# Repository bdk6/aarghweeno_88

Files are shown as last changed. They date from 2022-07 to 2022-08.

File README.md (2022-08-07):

# aarghweeno_88
An Arduino compatible prototyping board

Short story: add prototyping area to Arduino compatible AVR development board.

I have been a fan of the AVR processors for a long time.  My first project with them was in 2006.  The Arduino came along later and it is a neat system, making it very easy to get started.  When I say "Arduino" I mean AVR based ones.  If I should refer to some other, I'll specify.  

Now you can get an Aruino Nano clone for less than $5 US all over the web.  But one thing that has often bothered me about all the standard Arduino boards is that they don't have onbaord prototyping areas.  This little project aims to fix that.

The board is 3.9 x 3.9 inches, just under the 100 x 100 mm size of JLCPCBs cheapest PC board service.  About 1 1/2 inch along the "top" edge holds the AVR, regulator, programming header, and associated components.  The rest of the board is taken up with a prototyping area of holes on 0.1" centers arranged in groups of threes and long rows of bus connections.  There are also four mounting holes, another thing absent from standard Arduinos.  The idea is you can build an entire project on a single board without all those "dupont" (I hate that name) wires and whatnot crap going from board to board.

The one thing I left off that I agonized over was a USB interface or any type of serial port circuit.  Many of my projects don't need either and I generally prefer to use an AVR programmer to flash the chip.  If you really need/want a USB interface you can add it in the proto area.  You might need an SMD to DIP adapter or maybe just buy a USB to 5V serial module with 0.1" header pins.

You are welcome to use this board for any purpose, personal or commercial, as long as you leave the copyright notice in place.  I would like to know about any projects you build with it or comments in general.  If you make enough money selling it to hire Bill Gates and Jeff Bezos as your house boys, I wouldn't mind if you slipped me a mil or two.

20220807   First set of boards
I got the first boards back from JLCPCB on Thursday.  Friday morning I started soldering one up.  After replacing the LED that I soldered in backward, everthing seems to be working fine.  A bit more testing to do, but so far, so good.



Today I cleaned up some minor flaws and I'm releasing version 1.1.  Changed to value of C3 (to 0.1 uF from 0.33 uF) and cleaned up some silkscreen.  No substantive changes.  I plan to run a set of these once I've tested the first one more.

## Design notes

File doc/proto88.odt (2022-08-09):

Proto 88 Board

ver 1.1.0

August 7, 2022

Will Cooke

1. Introduction

The Proto-88 board is an AVR development board for use with various 28 pin DIP AVR microcontrollers. The ATMega8, ATMega88, ATMega168, and ATMega328 can all be used. The PC board has onboard circuitry for the basic microcontroller and a large prototyping area. The board is Arduino compatible, but there is no built-in USB circuitry for bootloading.

The hardware design is open source. The gerber files needed to have the board manufactured are available online. Feel free to have as many made as you like. You are welcome to do what you want with them, including selling them. If you do make millions of dollars selling them, please remember where you got it. One stipulation – you MUST keep the copyright notice on the board.

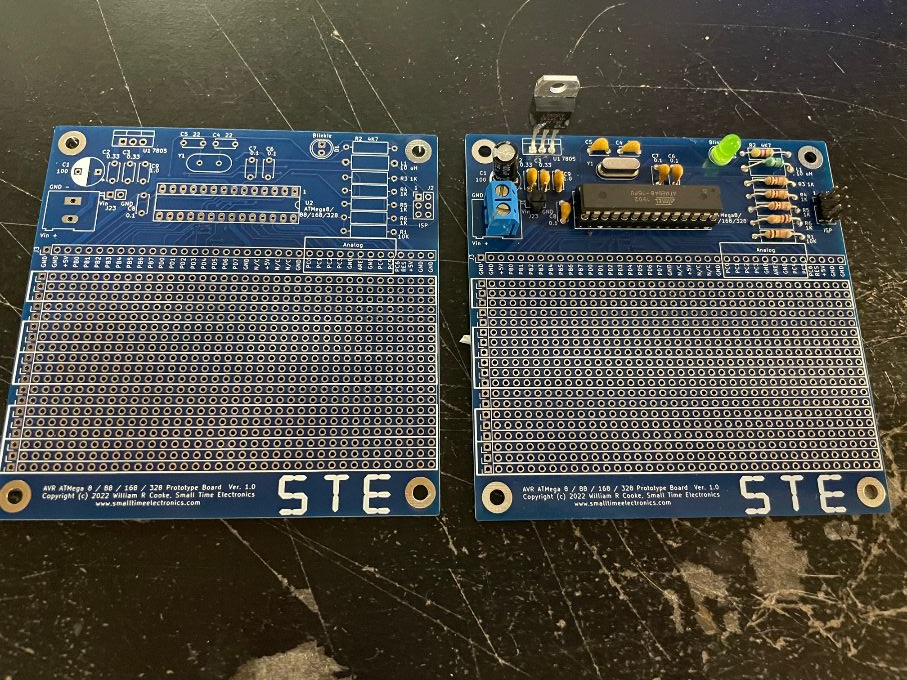
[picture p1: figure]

2. Overview

This is a simple board with just basic necessities of building an AVR project. The board includes the most common things needed and is mostly prototyping area. I have wanted this and intended to build it for a very long time. Before this the two alternatives I had were: 1) build the entire AVR circuit on a common, generic prototyping board, duplicating the same circuitry over and over, and 2) use an Arduino (Nano) and solder it onto a generic proto board. To me, this is a much better solution. I suspect other people will feel the same way.

The board’s features:

- Processor: Can use ATMega8, ATMega88, ATMega168, ATMega328 in narrow DIP 28 package.
- Crystal oscillator circuit.
- Power input connector and filtering.
- Voltage regulator. LM7805 or pin compatible.
- Filtering for Analog VCC.
- Prototyping connections to all processor pins as well as input voltage.
- Programming header (AVR ISP 6 pin.)
- Large prototyping area with 3 hole strips and long power bus strips.
- Arduino compatible.

Schematic and Parts List:

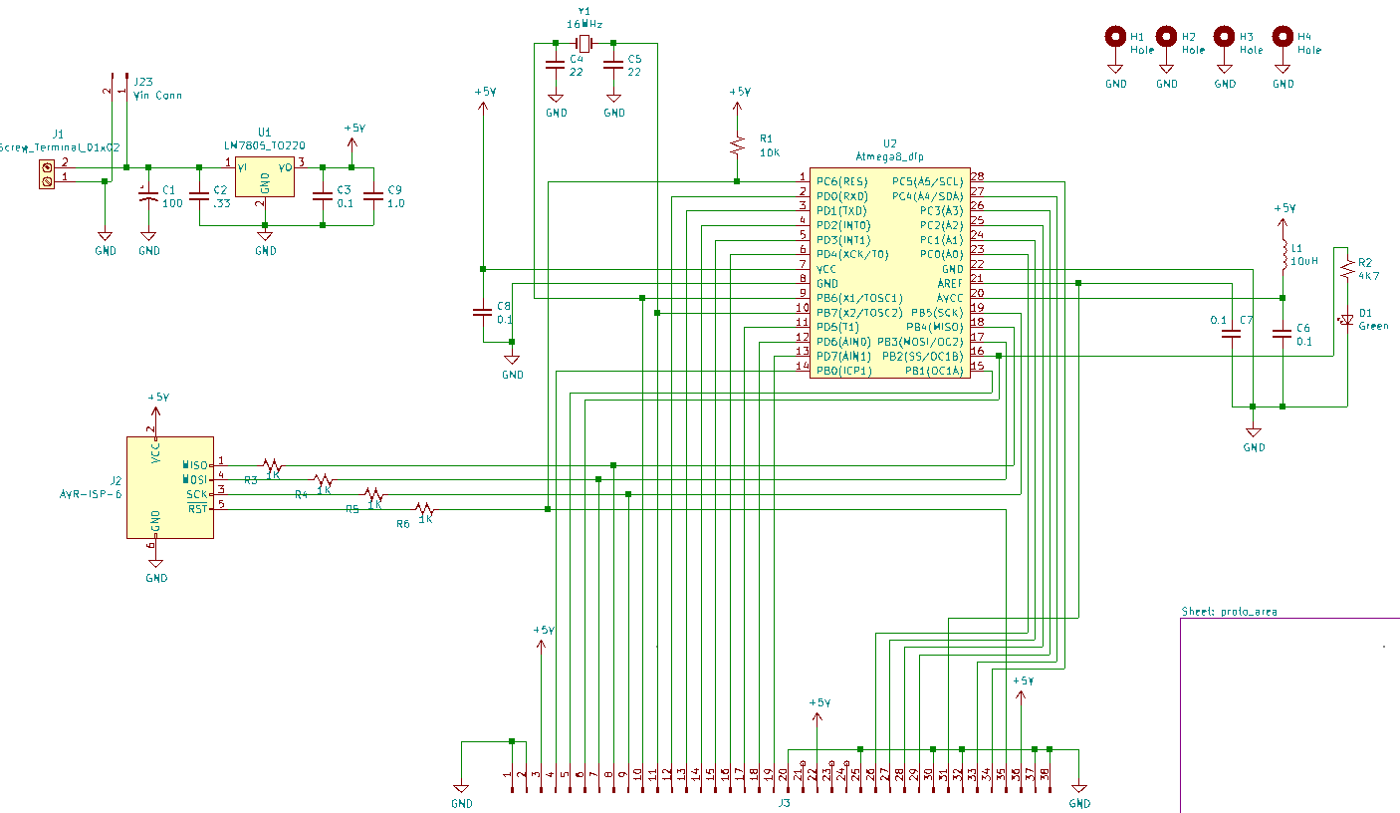
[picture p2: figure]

Parts List

C1 100 uF electrolytic capacacitor 5.04 mm

C2 0.33 uF ceramic capacitor 5.04mm

C3,C6,C7,C8 0.1 uF ceramic capacitor 5.04 mm

C4,C5 22 pF ceramic capacitor 5.04mm

C5 22 pF ceramic capacitor 5.04 mm

C9 1.0 uF ceramic capacitor 5.04 mm

D1 LED, T1 ¾ through hole green

J1 1x2 5mm terminal block

J2 2x3 pin header 2.54 mm AVR ISP connector

J23 1x2 pin header 2.54 mm

L1 10 uH axial leaded inductor (Tayda ???)

R1 10K 1/8 watt through hole

R2 4K7 1/8 watt through hole

R3,R4,R5,R6 1K 1/8 watt through hole

U1` LM7805 TO220 voltage regulator

U2 AVR ATMega8, 48, 88, 168, 328, etc

Y1 16 MHz quartz crystal in HC49 package

Configuration:

power section – It is possible to leave off most of the power input section. The power input terminal block, J1, can be omitted and wires soldered directly to the board. If the board will be powered by a regulated or otherwise acceptable voltage, the LM7805 regulator and C2 and C3 can be left off. A jumper will need to be wired from pin 1 to pin 3 of the regulator position. It’s a good idea to leave C1 and C9 to filter the incoming power. If you have another regulator that is pin compatible, as are many low-dropout regulators, it can be used instead of the LM7805. The two pin header, J23, can be left off in most cases. It connects directly to the power inputs on J1. Its purpose is to make the input power easily available to the prototype area with wires soldered into the holes instead of a header.

CPU – A number of different CPUs can be used. The ATMega8, ATMega88, ATMega168, ATMega328 and probably others (ATMega48, etc) can all be used. They must be in the “narrow” (0.3 inch) 28 pin DIP package. L1 is for filtering the analog to digital converter (ADC) power supply. If you aren’t using the ADC or if the normal CPU power is good enough for your uses, you can replace L1 with a wire jumper and do without the extra filtering. It is recommended to leave the capacitor, C6, in any case.

Programming Header – If for some reason you don’t need the programming header, J2, it and resistors R3, R4, R5, and R6 can be left off.

LED – Under no circumstances should D1 and R2 be left off! People will say bad things about your mother if you build a microcontroller prototyping board without a blinkie light!

The board can be built in many different configurations based on your needs and desires, as well as parts you have on hand.

Prototyping:

They prototype area consists of five rows of 3-hole connected pads on 0.1 inch centers to hold components and wires. Four of the rows are grouped in twos and adjacent to each other to accommodate larger components (e.g. 0.6 inch ICs.) Between the three sections of 3-hole pads are bus strips. There are a total of four strips arranged in two groups of two. The bus strips are independent and not connected to each other or anything else. They would typically be used for power rails (Vcc and GND) but that is not a requirement. You will need to connect them to whatever you desire them to be.

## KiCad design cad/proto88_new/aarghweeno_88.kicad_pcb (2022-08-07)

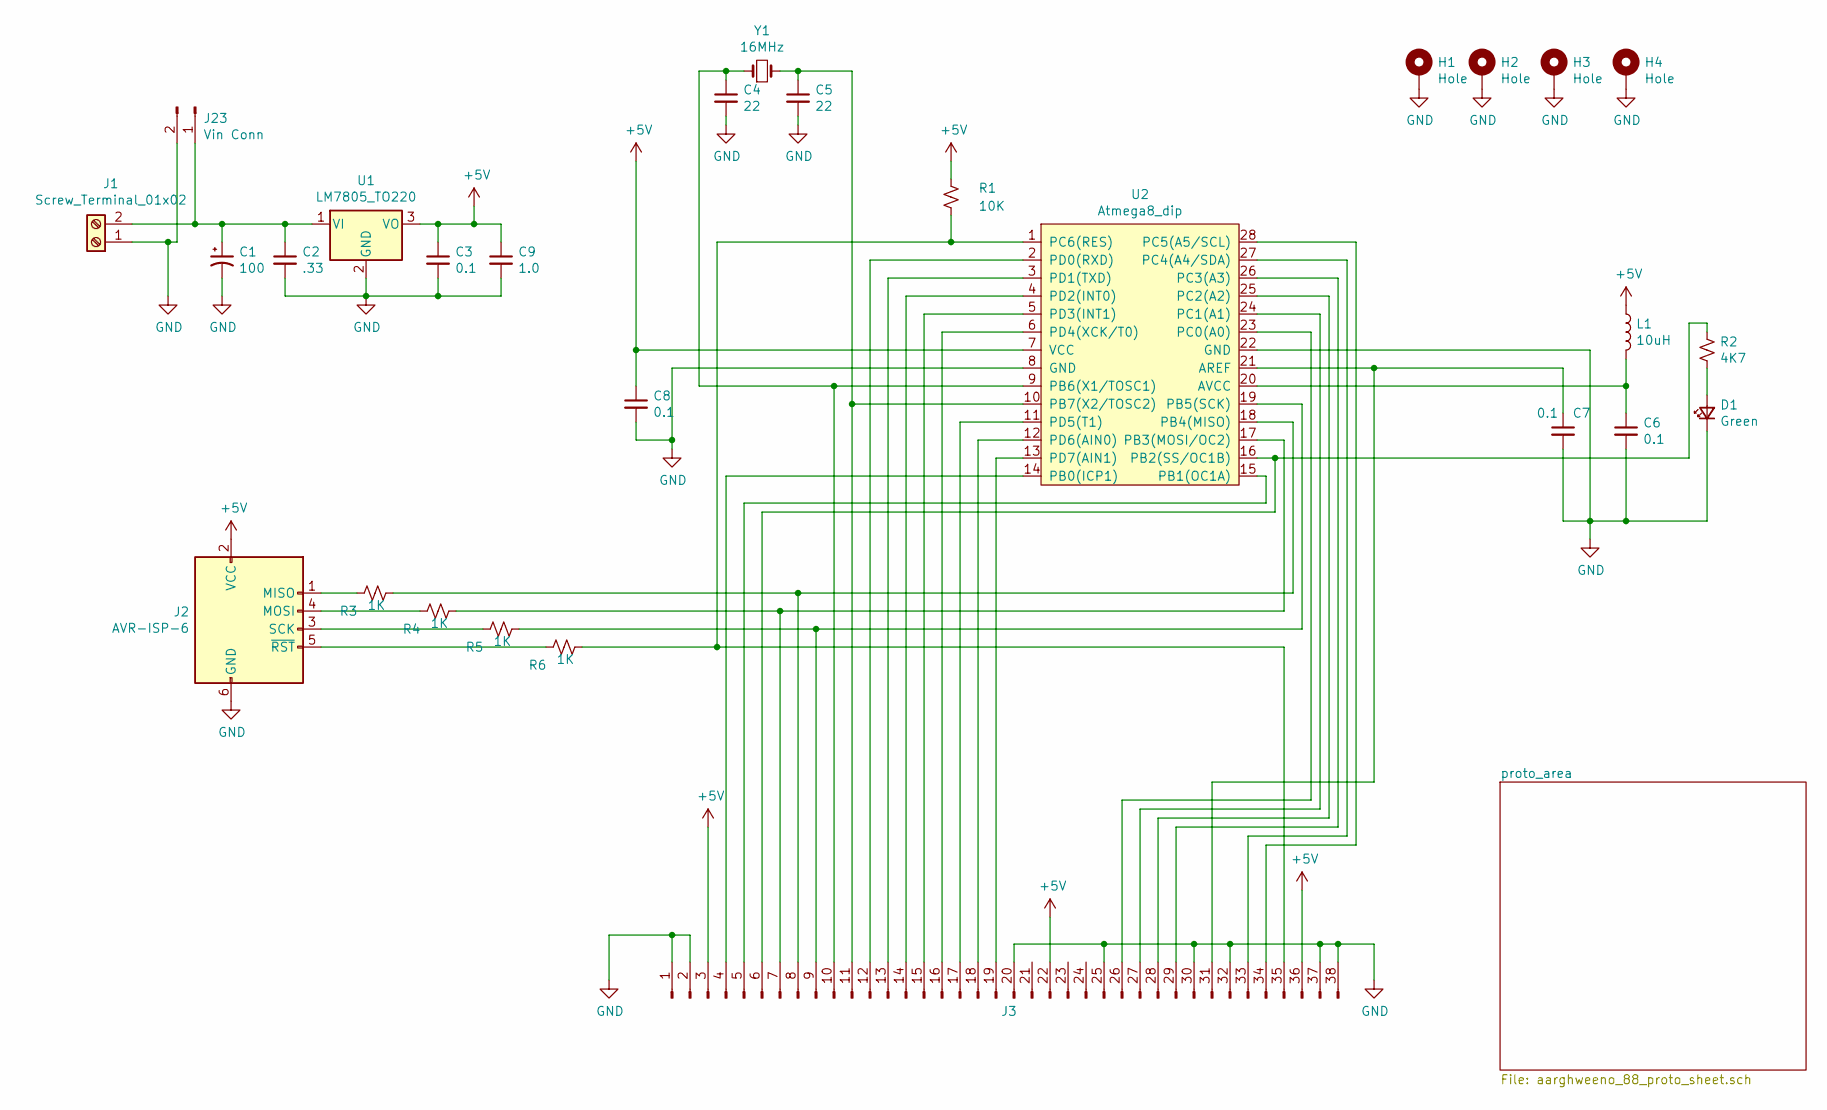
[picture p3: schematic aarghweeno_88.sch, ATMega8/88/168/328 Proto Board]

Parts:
C1: 100; CP_Radial_D8.0mm_P5.00mm
C2: .33; C_Disc_D5.0mm_W2.5mm_P5.00mm
C3, C6, C7, C8: 0.1; C_Disc_D5.0mm_W2.5mm_P5.00mm
C4, C5: 22; C_Disc_D5.0mm_W2.5mm_P5.00mm
C9: 1.0; C_Disc_D5.0mm_W2.5mm_P5.00mm
D1: Green; LED_D5.0mm
H1, H2, H3, H4: Hole; MountingHole_3.5mm_Pad
J1: Screw_Terminal_01x02; TerminalBlock_Altech_AK300-2_P5.00mm
J2: AVR-ISP-6; PinHeader_2x03_P2.54mm_Vertical
J3: Conn_01x38_Male; ProtoStrip_1x38_P2.54mm_Vertical
J23: Vin Conn; PinHeader_1x02_P2.54mm_Vertical
L1: 10uH; L_Axial_L9.5mm_D4.0mm_P12.70mm_Horizontal_Fastron_SMCC
R1: 10K; R_Axial_DIN0309_L9.0mm_D3.2mm_P12.70mm_Horizontal
R2: 4K7; R_Axial_DIN0309_L9.0mm_D3.2mm_P12.70mm_Horizontal
R3, R4, R5, R6: 1K; R_Axial_DIN0309_L9.0mm_D3.2mm_P12.70mm_Horizontal
U1: LM7805_TO220; TO-220-3_Vertical
U2: Atmega8_dip; DIP-28_W7.62mm_Socket_LongPads
Y1: 16MHz; Crystal_HC49-U_Vertical

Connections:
+5V: C3.1, C8.1, C9.1, J2.2 (VCC), J3.3, J3.22, J3.36, L1.1, R1.1, U1.3 (VO), U2.7 (VCC)
GND: C1.2, C2.2, C3.2, C4.2, C5.2, C6.2, C7.2, C8.2, C9.2, D1.1 (K), H1.1, H2.1, H3.1, H4.1, J1.1, J2.6 (GND), J3.1, J3.2, J3.20, J3.25, J3.30, J3.32, J3.37, J3.38, J23.2, U1.2 (GND), U2.8 (GND), U2.22 (GND)
unnamed: C1.1, C2.1, J1.2, J23.1, U1.1 (VI)
unnamed: C4.1, J3.10, U2.9 (PB6(X1/TOSC1)), Y1.1
unnamed: C5.1, J3.11, U2.10 (PB7(X2/TOSC2)), Y1.2
unnamed: C6.1, L1.2, U2.20 (AVCC)
unnamed: C7.1, J3.31, U2.21 (AREF)
unnamed: D1.2 (A), R2.2
unnamed: J2.1 (MISO), R3.2
unnamed: J2.3 (SCK), R5.2
unnamed: J2.4 (MOSI), R4.2
unnamed: J2.5 (~RST), R6.2
unnamed: J3.4, U2.14 (PB0(ICP1))
unnamed: J3.5, U2.15 (PB1(OC1A))
unnamed: J3.6, R2.1, U2.16 (PB2(SS/OC1B))
unnamed: J3.7, R4.1, U2.17 (PB3(MOSI/OC2))
unnamed: J3.8, R3.1, U2.18 (PB4(MISO))
unnamed: J3.9, R5.1, U2.19 (PB5(SCK))
unnamed: J3.12, U2.2 (PD0(RXD))
unnamed: J3.13, U2.3 (PD1(TXD))
unnamed: J3.14, U2.4 (PD2(INT0))
unnamed: J3.15, U2.5 (PD3(INT1))
unnamed: J3.16, U2.6 (PD4(XCK/T0))
unnamed: J3.17, U2.11 (PD5(T1))
unnamed: J3.18, U2.12 (PD6(AIN0))
unnamed: J3.19, U2.13 (PD7(AIN1))
unnamed: J3.26, U2.23 (PC0(A0))
unnamed: J3.27, U2.24 (PC1(A1))
unnamed: J3.28, U2.25 (PC2(A2))
unnamed: J3.29, U2.26 (PC3(A3))
unnamed: J3.33, U2.27 (PC4(A4/SDA))
unnamed: J3.34, U2.28 (PC5(A5/SCL))
unnamed: J3.35, R1.2, R6.1, U2.1 (PC6(RES))

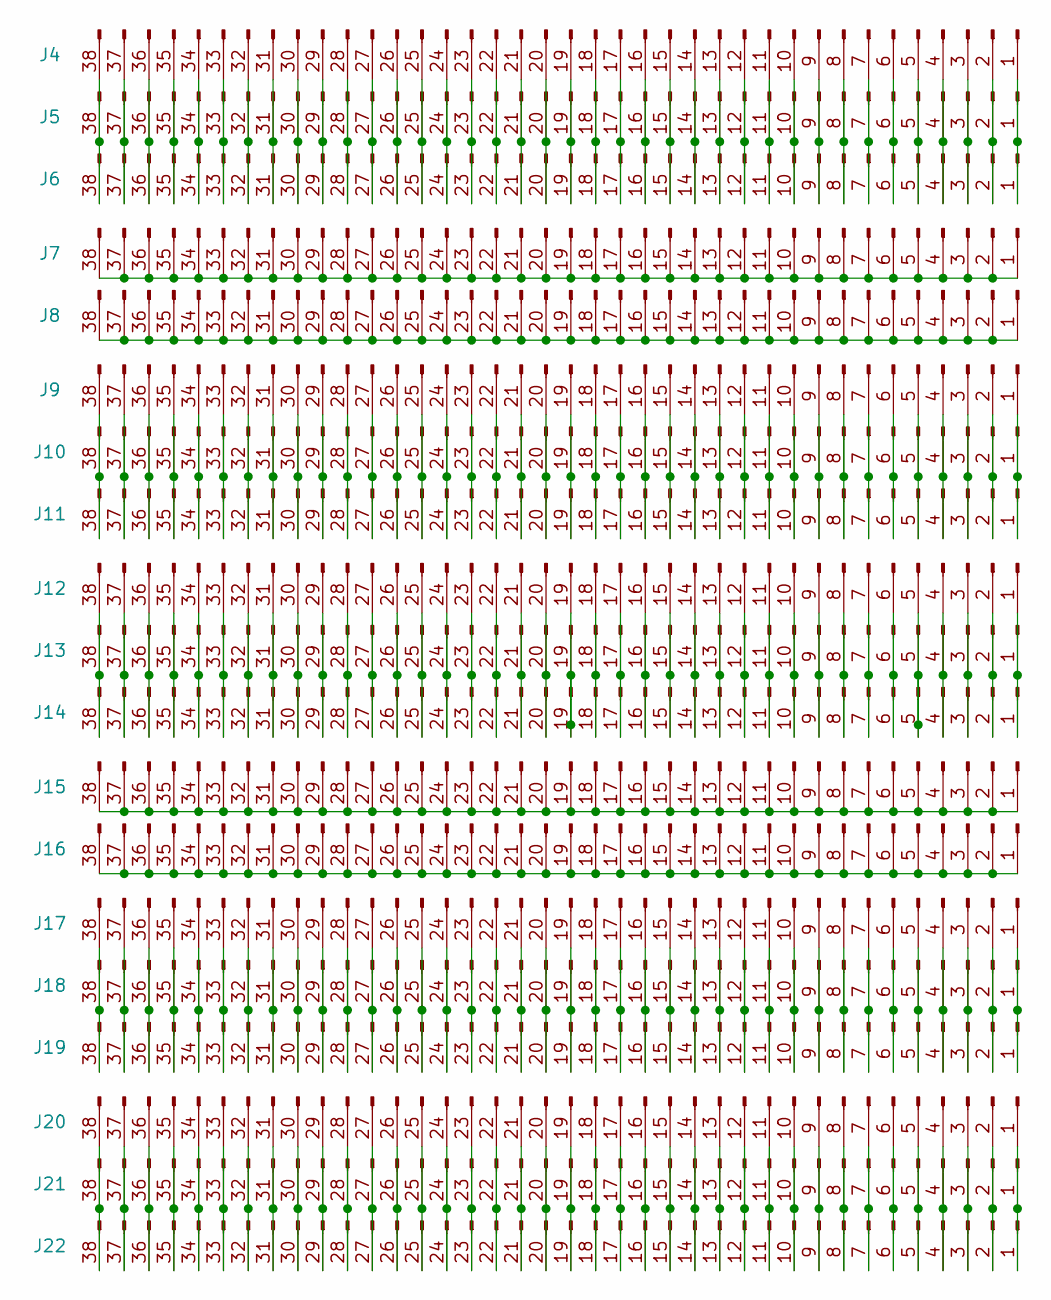
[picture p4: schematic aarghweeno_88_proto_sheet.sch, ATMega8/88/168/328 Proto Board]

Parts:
J4, J5, J6, J7, J8, J9, J10, J11, J12, J13, J14, J15, J16, J17, J18, J19, J20, J21, J22: Conn_01x38_Male; ProtoStrip_1x38_P2.54mm_Vertical

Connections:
unnamed: J4.1, J5.1, J6.1
unnamed: J4.2, J5.2, J6.2
unnamed: J4.3, J5.3, J6.3
unnamed: J4.4, J5.4, J6.4
unnamed: J4.5, J5.5, J6.5
unnamed: J4.6, J5.6, J6.6
unnamed: J4.7, J5.7, J6.7
unnamed: J4.8, J5.8, J6.8
unnamed: J4.9, J5.9, J6.9
unnamed: J4.10, J5.10, J6.10
unnamed: J4.11, J5.11, J6.11
unnamed: J4.12, J5.12, J6.12
unnamed: J4.13, J5.13, J6.13
unnamed: J4.14, J5.14, J6.14
unnamed: J4.15, J5.15, J6.15
unnamed: J4.16, J5.16, J6.16
unnamed: J4.17, J5.17, J6.17
unnamed: J4.18, J5.18, J6.18
unnamed: J4.19, J5.19, J6.19
unnamed: J4.20, J5.20, J6.20
unnamed: J4.21, J5.21, J6.21
unnamed: J4.22, J5.22, J6.22
unnamed: J4.23, J5.23, J6.23
unnamed: J4.24, J5.24, J6.24
unnamed: J4.25, J5.25, J6.25
unnamed: J4.26, J5.26, J6.26
unnamed: J4.27, J5.27, J6.27
unnamed: J4.28, J5.28, J6.28
unnamed: J4.29, J5.29, J6.29
unnamed: J4.30, J5.30, J6.30
unnamed: J4.31, J5.31, J6.31
unnamed: J4.32, J5.32, J6.32
unnamed: J4.33, J5.33, J6.33
unnamed: J4.34, J5.34, J6.34
unnamed: J4.35, J5.35, J6.35
unnamed: J4.36, J5.36, J6.36
unnamed: J4.37, J5.37, J6.37
unnamed: J4.38, J5.38, J6.38
unnamed: J7.1, J7.2, J7.3, J7.4, J7.5, J7.6, J7.7, J7.8, J7.9, J7.10, J7.11, J7.12, J7.13, J7.14, J7.15, J7.16, J7.17, J7.18, J7.19, J7.20, J7.21, J7.22, J7.23, J7.24, J7.25, J7.26, J7.27, J7.28, J7.29, J7.30, J7.31, J7.32, J7.33, J7.34, J7.35, J7.36, J7.37, J7.38
unnamed: J8.1, J8.2, J8.3, J8.4, J8.5, J8.6, J8.7, J8.8, J8.9, J8.10, J8.11, J8.12, J8.13, J8.14, J8.15, J8.16, J8.17, J8.18, J8.19, J8.20, J8.21, J8.22, J8.23, J8.24, J8.25, J8.26, J8.27, J8.28, J8.29, J8.30, J8.31, J8.32, J8.33, J8.34, J8.35, J8.36, J8.37, J8.38
unnamed: J9.1, J10.1, J11.1
unnamed: J9.2, J10.2, J11.2
unnamed: J9.3, J10.3, J11.3
unnamed: J9.4, J10.4, J11.4
unnamed: J9.5, J10.5, J11.5
unnamed: J9.6, J10.6, J11.6
unnamed: J9.7, J10.7, J11.7
unnamed: J9.8, J10.8, J11.8
unnamed: J9.9, J10.9, J11.9
unnamed: J9.10, J10.10, J11.10
unnamed: J9.11, J10.11, J11.11
unnamed: J9.12, J10.12, J11.12
unnamed: J9.13, J10.13, J11.13
unnamed: J9.14, J10.14, J11.14
unnamed: J9.15, J10.15, J11.15
unnamed: J9.16, J10.16, J11.16
unnamed: J9.17, J10.17, J11.17
unnamed: J9.18, J10.18, J11.18
unnamed: J9.19, J10.19, J11.19
unnamed: J9.20, J10.20, J11.20
unnamed: J9.21, J10.21, J11.21
unnamed: J9.22, J10.22, J11.22
unnamed: J9.23, J10.23, J11.23
unnamed: J9.24, J10.24, J11.24
unnamed: J9.25, J10.25, J11.25
unnamed: J9.26, J10.26, J11.26
unnamed: J9.27, J10.27, J11.27
unnamed: J9.28, J10.28, J11.28
unnamed: J9.29, J10.29, J11.29
unnamed: J9.30, J10.30, J11.30
unnamed: J9.31, J10.31, J11.31
unnamed: J9.32, J10.32, J11.32
unnamed: J9.33, J10.33, J11.33
unnamed: J9.34, J10.34, J11.34
unnamed: J9.35, J10.35, J11.35
unnamed: J9.36, J10.36, J11.36
unnamed: J9.37, J10.37, J11.37
unnamed: J9.38, J10.38, J11.38
unnamed: J12.1, J13.1, J14.1
unnamed: J12.2, J13.2, J14.2
unnamed: J12.3, J13.3, J14.3
unnamed: J12.4, J13.4, J14.4
unnamed: J12.5, J13.5, J14.5
unnamed: J12.6, J13.6, J14.6
unnamed: J12.7, J13.7, J14.7
unnamed: J12.8, J13.8, J14.8
unnamed: J12.9, J13.9, J14.9
unnamed: J12.10, J13.10, J14.10
unnamed: J12.11, J13.11, J14.11
unnamed: J12.12, J13.12, J14.12
unnamed: J12.13, J13.13, J14.13
unnamed: J12.14, J13.14, J14.14
unnamed: J12.15, J13.15, J14.15
unnamed: J12.16, J13.16, J14.16
unnamed: J12.17, J13.17, J14.17
unnamed: J12.18, J13.18, J14.18
unnamed: J12.19, J13.19, J14.19
unnamed: J12.20, J13.20, J14.20
unnamed: J12.21, J13.21, J14.21
unnamed: J12.22, J13.22, J14.22
unnamed: J12.23, J13.23, J14.23
unnamed: J12.24, J13.24, J14.24
unnamed: J12.25, J13.25, J14.25
unnamed: J12.26, J13.26, J14.26
unnamed: J12.27, J13.27, J14.27
unnamed: J12.28, J13.28, J14.28
unnamed: J12.29, J13.29, J14.29
unnamed: J12.30, J13.30, J14.30
unnamed: J12.31, J13.31, J14.31
unnamed: J12.32, J13.32, J14.32
unnamed: J12.33, J13.33, J14.33
unnamed: J12.34, J13.34, J14.34
unnamed: J12.35, J13.35, J14.35
unnamed: J12.36, J13.36, J14.36
unnamed: J12.37, J13.37, J14.37
unnamed: J12.38, J13.38, J14.38
unnamed: J15.1, J15.2, J15.3, J15.4, J15.5, J15.6, J15.7, J15.8, J15.9, J15.10, J15.11, J15.12, J15.13, J15.14, J15.15, J15.16, J15.17, J15.18, J15.19, J15.20, J15.21, J15.22, J15.23, J15.24, J15.25, J15.26, J15.27, J15.28, J15.29, J15.30, J15.31, J15.32, J15.33, J15.34, J15.35, J15.36, J15.37, J15.38
unnamed: J16.1, J16.2, J16.3, J16.4, J16.5, J16.6, J16.7, J16.8, J16.9, J16.10, J16.11, J16.12, J16.13, J16.14, J16.15, J16.16, J16.17, J16.18, J16.19, J16.20, J16.21, J16.22, J16.23, J16.24, J16.25, J16.26, J16.27, J16.28, J16.29, J16.30, J16.31, J16.32, J16.33, J16.34, J16.35, J16.36, J16.37, J16.38
unnamed: J17.1, J18.1, J19.1
unnamed: J17.2, J18.2, J19.2
unnamed: J17.3, J18.3, J19.3
unnamed: J17.4, J18.4, J19.4
unnamed: J17.5, J18.5, J19.5
unnamed: J17.6, J18.6, J19.6
unnamed: J17.7, J18.7, J19.7
unnamed: J17.8, J18.8, J19.8
unnamed: J17.9, J18.9, J19.9
unnamed: J17.10, J18.10, J19.10
unnamed: J17.11, J18.11, J19.11
unnamed: J17.12, J18.12, J19.12
unnamed: J17.13, J18.13, J19.13
unnamed: J17.14, J18.14, J19.14
unnamed: J17.15, J18.15, J19.15
unnamed: J17.16, J18.16, J19.16
unnamed: J17.17, J18.17, J19.17
unnamed: J17.18, J18.18, J19.18
unnamed: J17.19, J18.19, J19.19
unnamed: J17.20, J18.20, J19.20
unnamed: J17.21, J18.21, J19.21
unnamed: J17.22, J18.22, J19.22
unnamed: J17.23, J18.23, J19.23
unnamed: J17.24, J18.24, J19.24
unnamed: J17.25, J18.25, J19.25
unnamed: J17.26, J18.26, J19.26
unnamed: J17.27, J18.27, J19.27
unnamed: J17.28, J18.28, J19.28
unnamed: J17.29, J18.29, J19.29
unnamed: J17.30, J18.30, J19.30
unnamed: J17.31, J18.31, J19.31
unnamed: J17.32, J18.32, J19.32
unnamed: J17.33, J18.33, J19.33
unnamed: J17.34, J18.34, J19.34
unnamed: J17.35, J18.35, J19.35
unnamed: J17.36, J18.36, J19.36
unnamed: J17.37, J18.37, J19.37
unnamed: J17.38, J18.38, J19.38
unnamed: J20.1, J21.1, J22.1
unnamed: J20.2, J21.2, J22.2
unnamed: J20.3, J21.3, J22.3
unnamed: J20.4, J21.4, J22.4
unnamed: J20.5, J21.5, J22.5
unnamed: J20.6, J21.6, J22.6
unnamed: J20.7, J21.7, J22.7
unnamed: J20.8, J21.8, J22.8
unnamed: J20.9, J21.9, J22.9
unnamed: J20.10, J21.10, J22.10
unnamed: J20.11, J21.11, J22.11
unnamed: J20.12, J21.12, J22.12
unnamed: J20.13, J21.13, J22.13
unnamed: J20.14, J21.14, J22.14
unnamed: J20.15, J21.15, J22.15
unnamed: J20.16, J21.16, J22.16
unnamed: J20.17, J21.17, J22.17
unnamed: J20.18, J21.18, J22.18
unnamed: J20.19, J21.19, J22.19
unnamed: J20.20, J21.20, J22.20
unnamed: J20.21, J21.21, J22.21
unnamed: J20.22, J21.22, J22.22
unnamed: J20.23, J21.23, J22.23
unnamed: J20.24, J21.24, J22.24
unnamed: J20.25, J21.25, J22.25
unnamed: J20.26, J21.26, J22.26
unnamed: J20.27, J21.27, J22.27
unnamed: J20.28, J21.28, J22.28
unnamed: J20.29, J21.29, J22.29
unnamed: J20.30, J21.30, J22.30
unnamed: J20.31, J21.31, J22.31
unnamed: J20.32, J21.32, J22.32
unnamed: J20.33, J21.33, J22.33
unnamed: J20.34, J21.34, J22.34
unnamed: J20.35, J21.35, J22.35
unnamed: J20.36, J21.36, J22.36
unnamed: J20.37, J21.37, J22.37
unnamed: J20.38, J21.38, J22.38

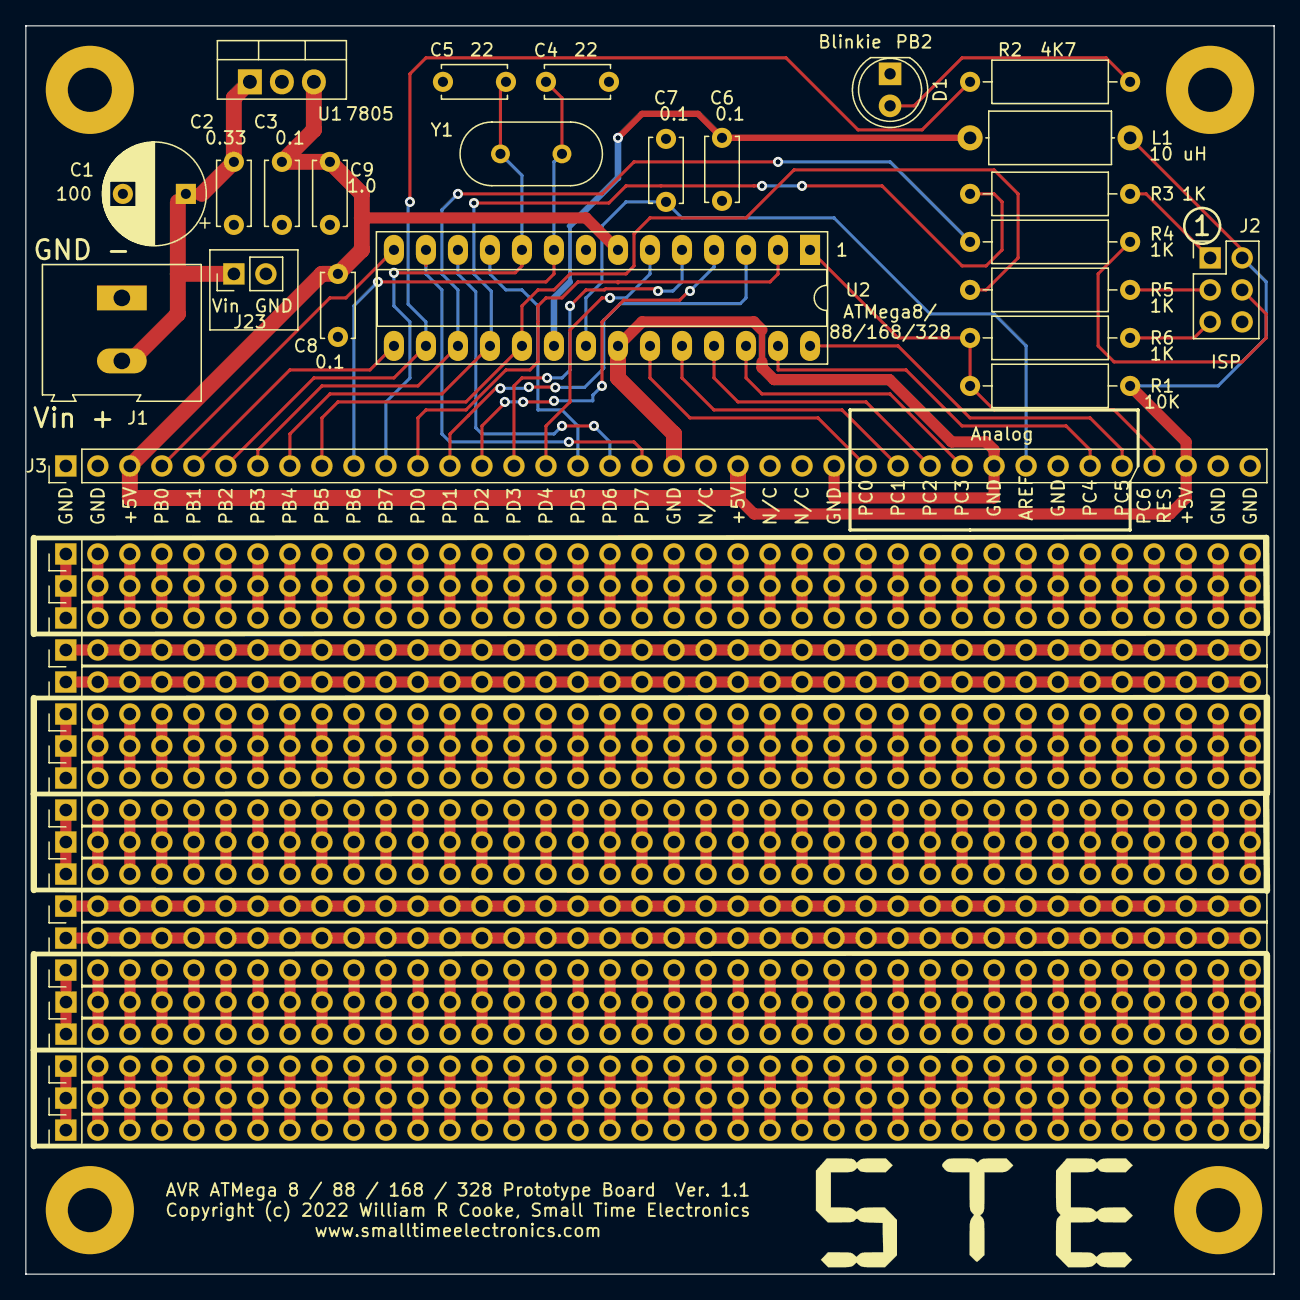
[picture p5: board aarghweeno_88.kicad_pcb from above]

Board: 2 copper layers, 99.1 x 99.1 mm, 47 parts (0 on the bottom side), 227 nets.

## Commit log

2022-07-21 Schematic and PCB nearly complete for ver 0.1
    [aarghweeno_88.kicad_pcb, aarghweeno_88.sch, aarghweeno_88_proto_sheet.sch]
2022-07-21 Release Candidate 1 ver 1.0
    [aarghweeno_88.kicad_pcb]
2022-07-21 Moved files around
    [aarghweeno_88.kicad_pcb, aarghweeno_88.sch, aarghweeno_88_proto_sheet.sch]
2022-07-21 Created Gerbers and zip for manufacture.
    [aarghweeno_88-B_Cu.gbl, aarghweeno_88-B_Mask.gbs, aarghweeno_88-B_Paste.gbp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]
2022-08-07 Changed reg cap value, changed version, added port# to LED, cleaned up silkscreen.
    [aarghweeno_88-B_Cu.gbr, aarghweeno_88-B_Mask.gbr, aarghweeno_88-B_Mask.gbs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]
2022-08-07 Removed old files
    [aarghweeno_88.kicad_pcb, aarghweeno_88.sch, aarghweeno_88_proto_sheet.sch]

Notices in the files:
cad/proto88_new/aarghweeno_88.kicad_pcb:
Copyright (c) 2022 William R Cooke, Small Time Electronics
